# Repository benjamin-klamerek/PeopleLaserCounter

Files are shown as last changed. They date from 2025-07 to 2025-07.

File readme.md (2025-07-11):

# 🧑‍🔬 PeopleLaserCounter

## License

<br />This work is licensed under a <a rel="license" href="http://creativecommons.org/licenses/by-nc-sa/4.0/">Creative Commons Attribution-NonCommercial-ShareAlike 4.0 International License</a>.

## 🎯 Objectif du projet

Système de comptage de personnes utilisant des **capteurs analogiques** (comme des lasers ou photodiodes) et une **carte Arduino**. Il permet de **détecter** et **compter** les passages à l’entrée et à la sortie d’un lieu.

Le compteur peut être :
- Automatiquement mis à jour via des **capteurs analogiques (lasers)**.
- Manuellement contrôlé à l’aide de **boutons physiques**.

L’objectif principal est de **transmettre régulièrement la valeur du compteur par communication RF (Radio Fréquence)** à un système distant.

---

## 🏗️ Architecture du projet

### 📁 Structure des fichiers

```bash
PeopleLaserCounter/
├── include/              # Fichiers d'en-tête génériques (README uniquement ici)
├── lib/                  # Bibliothèques additionnelles (non utilisées dans ce projet)
├── src/                  # Code source principal
│   ├── main.cpp          # Logique principale : détection + envoi RF
│   ├── counter.cpp       # Logique de comptage
│   ├── AnalogButton.cpp  # Détection analogique de type "laser"
│   └── *.h               # Fichiers d'en-tête
├── test/                 # Tests (README uniquement ici)
├── platformio.ini        # Configuration PlatformIO
└── .vscode/              # Config de l’environnement de dev (optionnel)
```

## ⚙️ Fonctionnalités module principal

### 🔌 Capteurs analogiques (Laser/Photodiode)
- 2 capteurs connectés aux broches **A0** et **A1**
- Détection de passage par dépassement d’un seuil : `LASER_THRESHOLD`

### 🔘 Boutons physiques
- **Incrémentation** : broche **2**
- **Décrémentation** : broche **3**
- **Reset long** (appui ≥ 3 secondes) : broche **4**

### 📡 Communication RF
- Utilisation de la bibliothèque **RCSwitch**
- Envoi des données toutes les **15 secondes** (ou à l'utilisation d'un bouton)
  - Modifiable via la constante `GLOBAL_REFRESH_RATE`
- Transmission via la broche **8**

### 🔧 Dépendances
- [`ezButton`](https://github.com/ArduinoGetStarted/ezButton)
- [`RCSwitch`](https://github.com/sui77/rc-switch)
- [`arduino-timer`](https://github.com/contrem/arduino-timer)

## ⚙️ Fonctionnalités module secondaire (compteur)

### 🔌 Afficheur LEDS
- Bandeau de LEDs à la broche **8**

### 📡 Communication RF
- Utilisation de la bibliothèque **RCSwitch**
- Réception via la broche **2**

### 🔧 Dépendances
- [`FastLED`](https://github.com/FastLED/FastLED)
- [`RCSwitch`](https://github.com/sui77/rc-switch)

---

## 📟 PCB

Initialement, le projet devrait être mis sur un seul PCB. Mais ce dernier peut être commun aux 2 modules en sélectionnant uniquement les connexions nécessaires.

[Fichier Gerber](PCB/PeopleLaserCounter-main.zip) qui peut être construit par un service en ligne.

Liste du matériel utilisé : 

- 2 alimentations 220V vers 12V (1A suffit pour le modules avec les lasers, il faut compteur plus pour le module LEDs mais cela dépend aussi du nombre de LEDs par segment)
- 2 Arduino UNO
- 2 modules HCW-P715 (12V vers 5V)
- Des LEDs adressables compatibles Arduino
- Un émetteur et récepteur radio fréquence 433Mhz compatible Arduino
- Des boutons, du fil, des cosses et des connecteurs divers (type jst xh en 2.54mm)

--- 

## 🧩 Les fichiers 3D STL

Vous pouvez trouver des boitiers pour impressions 3D dans le dossier [STL](/STL/)

Des inserts filetés pour vis M5 sont utilisés afin de fermer le boitier.

Les fichiers concernant l'affichage des nombres provient de ce projet : https://github.com/leonvandenbeukel/7-Segment-Digital-Clock-V2

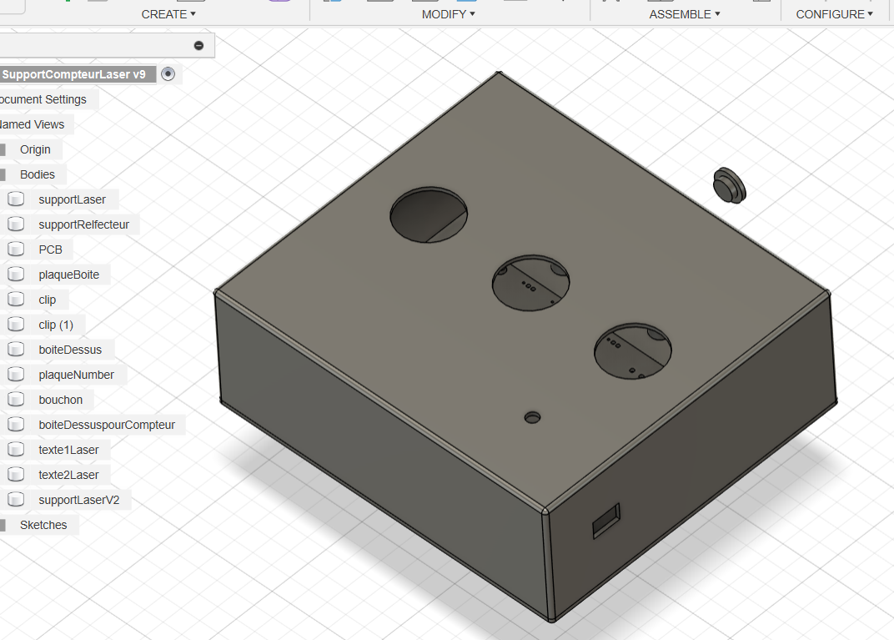
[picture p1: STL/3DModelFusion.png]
3DModel


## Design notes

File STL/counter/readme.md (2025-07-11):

These STL are from https://github.com/leonvandenbeukel/7-Segment-Digital-Clock-V2

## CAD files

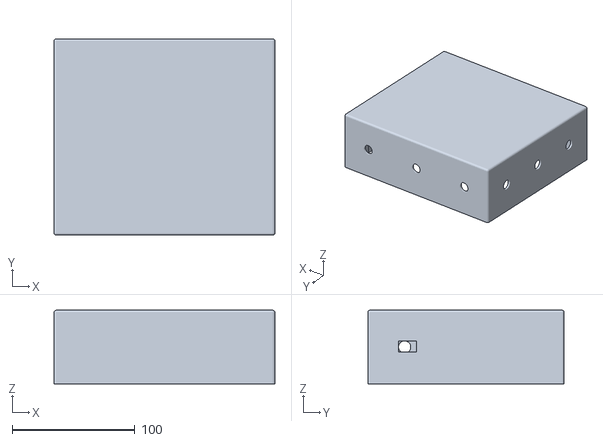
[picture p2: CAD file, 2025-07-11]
STL/boxes/boiteDessuspourCompteur.stl
180.0 x 160.0 x 60.0

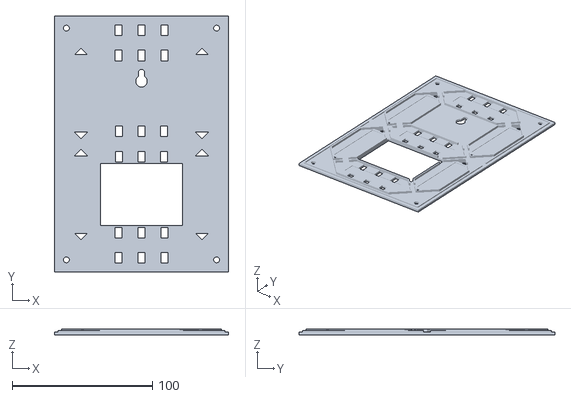
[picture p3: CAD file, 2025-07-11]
STL/counter/Bottom.stl
124.2 x 182.5 x 4.00

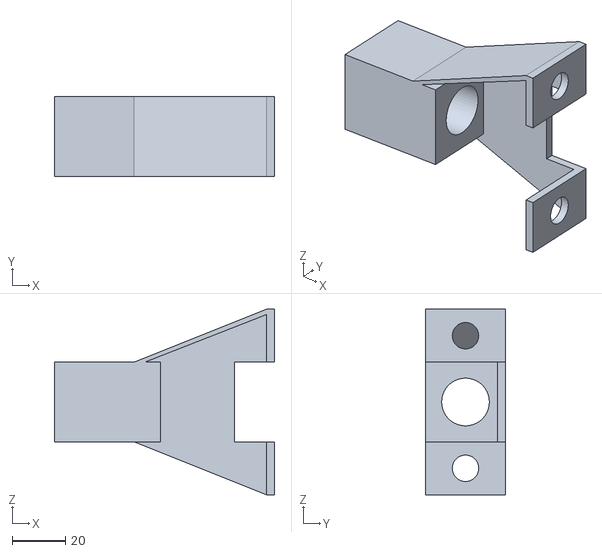
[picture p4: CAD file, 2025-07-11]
STL/boxes/supportLaserV2.stl
83.0 x 30.0 x 70.0

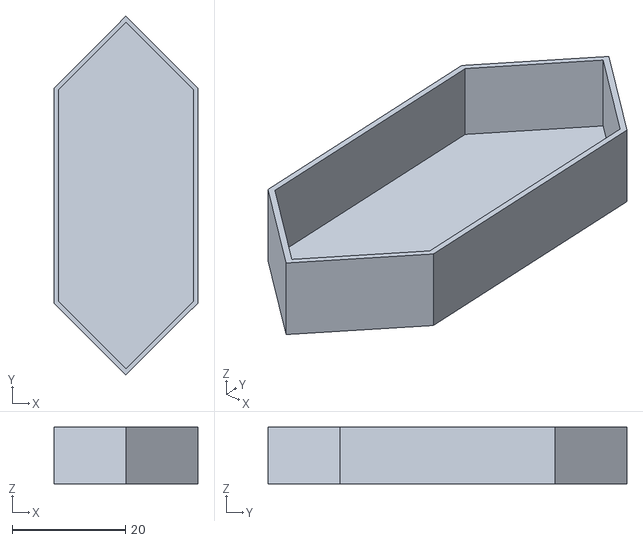
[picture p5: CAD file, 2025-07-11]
STL/counter/Segment_Vert_Flat.stl
25.4 x 63.5 x 10.00

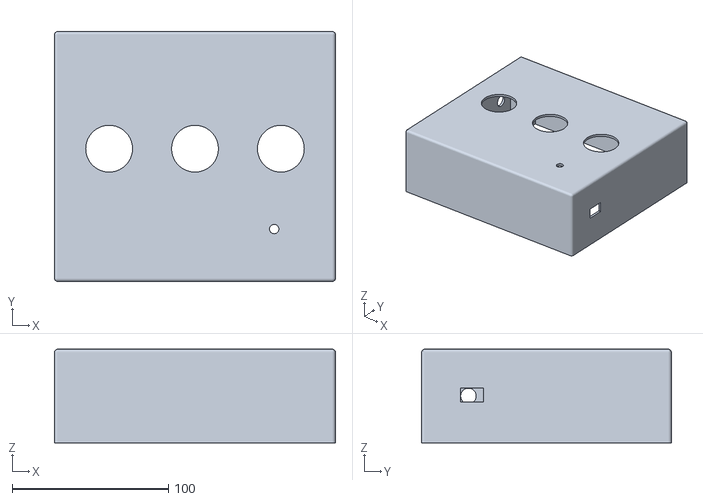
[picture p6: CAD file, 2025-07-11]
STL/boxes/boiteDessus.stl
180.0 x 160.0 x 60.0

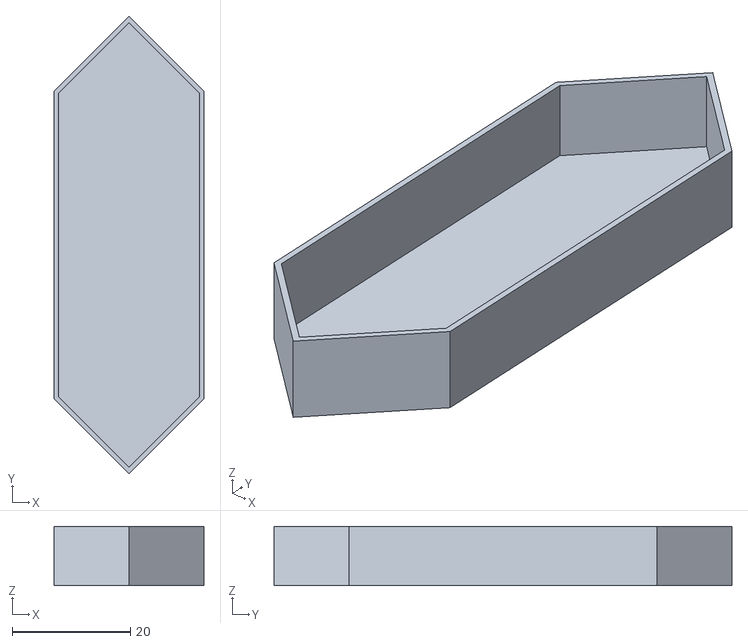
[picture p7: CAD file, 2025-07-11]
STL/counter/Segment_Hor_Flat.stl
25.4 x 77.5 x 10.0

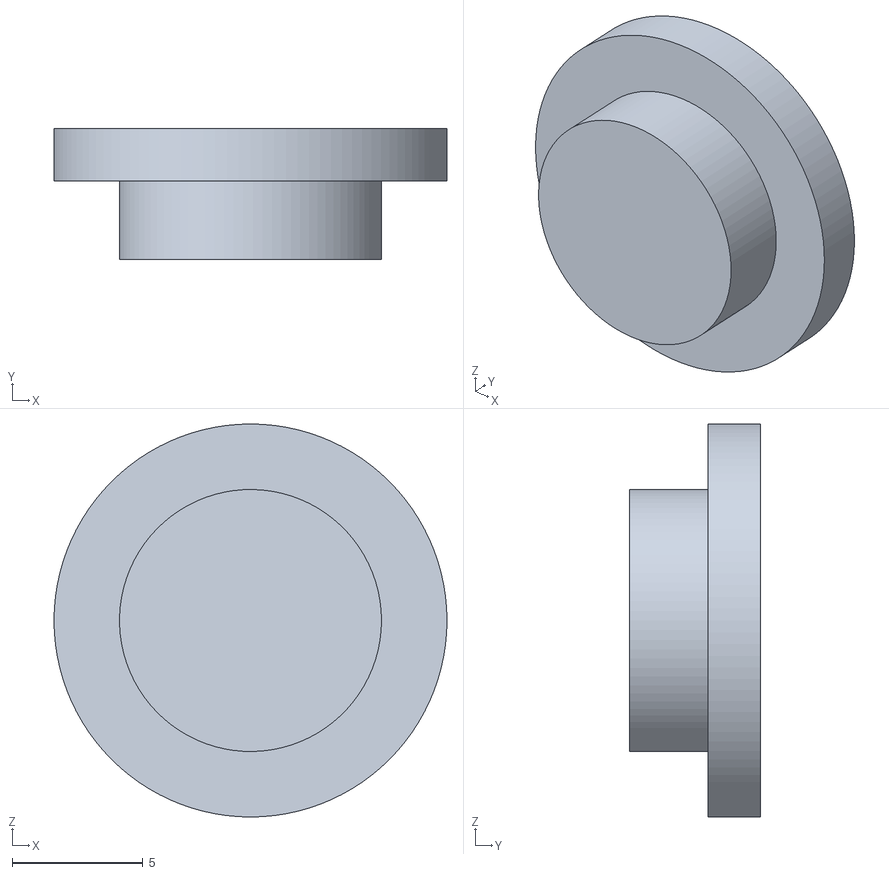
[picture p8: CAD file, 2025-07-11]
STL/boxes/bouchon.stl
15.0 x 5.00 x 15.0

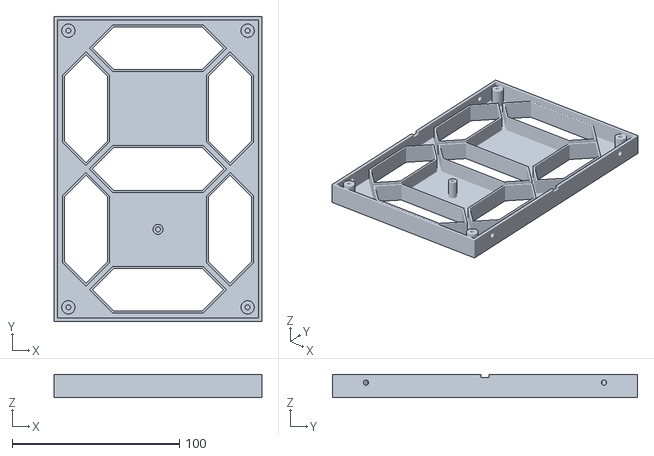
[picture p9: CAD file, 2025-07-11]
STL/counter/Top.stl
124.2 x 182.5 x 14.0

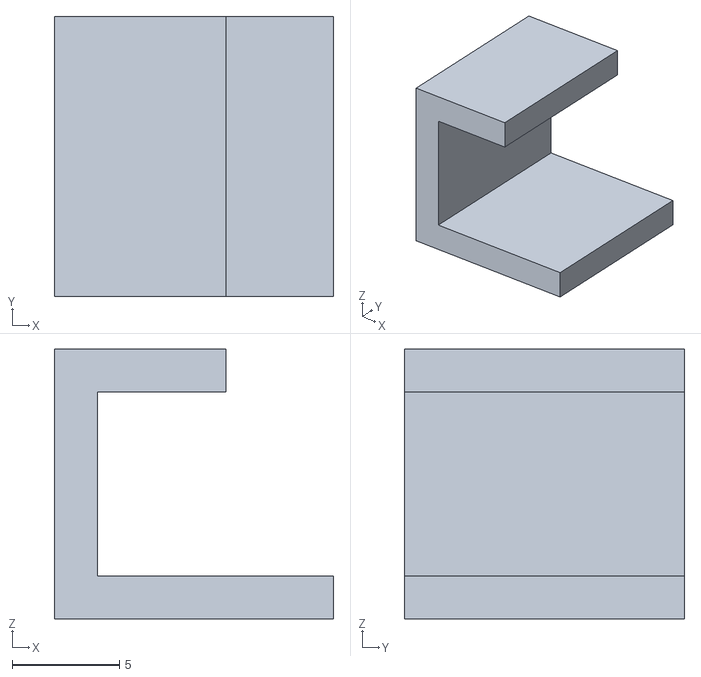
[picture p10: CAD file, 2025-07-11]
STL/boxes/clip.stl
13.0 x 13.0 x 12.5

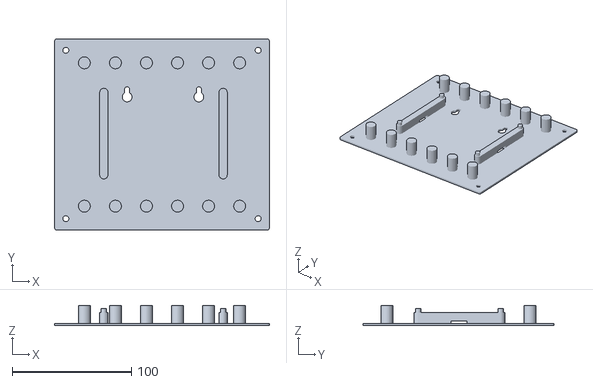
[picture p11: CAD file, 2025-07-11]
STL/boxes/plaqueBoite.stl
180.0 x 160.0 x 17.0

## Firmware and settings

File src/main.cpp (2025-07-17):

#include <Arduino.h>
#include <RCSwitch.h>
#include <ezButton.h>
#include <arduino-timer.h>
#include "AnalogButton.h"

#define COUNTER_LIMIT 1000
#define LASER_THRESHOLD 450
#define INVERT_PIN 6
#define PIN_RC 8
#define NB_BITS_TO_SEND 16
#define GLOBAL_REFRESH_RATE 15000     // ms
#define BUTTON_SHIFT_REFRESH_RATE 500 // ms
#define BUTTON_RESET_LONG_PRESS_TIME 3000 // ms

RCSwitch mySwitch = RCSwitch();

ezButton buttonAddOne(2);
ezButton buttonRemoveOne(3);
ezButton buttonReset(4);

AnalogButton laser1(A0, LASER_THRESHOLD);
AnalogButton laser2(A1, LASER_THRESHOLD);

// To be able to send 0, we use 1 as the first value (which is in fact 0)
int counter = 1;

//Too handle reset button long press
// We need to wait 3 seconds before resetting the counter
unsigned long resetPressStartTime = 0;
bool resetActionDone = true;

// Create a timer for periodic sending
// This timer will send the counter value every GLOBAL_REFRESH_RATE milliseconds
auto timerPeriodicSending = timer_create_default();

// Delay buttons sending to avoid flooding counter
auto timerButton = timer_create_default();

bool sendCounterValues(void *)
{
  mySwitch.send(counter, NB_BITS_TO_SEND);
  Serial.println("Counter SENT !");
  return true;
}

void scheduleNextSend()
{
  timerButton.cancel();
  timerButton.in(BUTTON_SHIFT_REFRESH_RATE, sendCounterValues);
}

void setup()
{
  mySwitch.enableTransmit(PIN_RC);
  mySwitch.setPulseLength(350);
  mySwitch.setProtocol(1);
  mySwitch.setRepeatTransmit(10);
  Serial.begin(9600);

  buttonAddOne.setDebounceTime(50);
  buttonRemoveOne.setDebounceTime(50);
  buttonReset.setDebounceTime(50);

  laser1.setDebounceTime(20);
  laser2.setDebounceTime(20);

  pinMode(INVERT_PIN, INPUT_PULLUP);

  timerPeriodicSending.every(GLOBAL_REFRESH_RATE, sendCounterValues);

  Serial.println("Arduino ready");
}

void increaseCounter()
{
  if (counter < COUNTER_LIMIT)
  {
    counter++;
    Serial.print("Counter increased : ");
    Serial.println(counter);
    scheduleNextSend();
  }
}

void decreaseCounter()
{
  if (counter > 1)
  {
    counter--;
    Serial.print("Counter decreased : ");
    Serial.println(counter);
    scheduleNextSend();
  }
}

void resetCounter()
{
  counter = 1;
  Serial.println("Counter reset to 0");
  sendCounterValues(nullptr);
}

void loopButtons()
{
  buttonAddOne.loop();
  buttonRemoveOne.loop();
  buttonReset.loop();
  if (buttonAddOne.isReleased())
  {
    increaseCounter();
  }
  else if (buttonRemoveOne.isReleased())
  {
    decreaseCounter();
  }

  if (buttonReset.isPressed())
  {
    resetPressStartTime = millis();
    resetActionDone = false;
  }

  if (buttonReset.getState() == LOW)
  {
    if (!resetActionDone && (millis() - resetPressStartTime >= BUTTON_RESET_LONG_PRESS_TIME))
    {
      resetCounter();
      resetActionDone = true;
    }
  }

  if (buttonReset.isReleased())
  {
    resetPressStartTime = 0;
    resetActionDone = false;
  }
}

void loopLasers()
{
  laser1.loop();
  laser2.loop();

  bool invert = digitalRead(INVERT_PIN);

  if (laser1.isPressed())
  {
    if (invert)
    {
      Serial.println("Laser 1 : +1");
      increaseCounter();
    }
    else
    {
      Serial.println("Laser 1 : -1");
      decreaseCounter();
    }
  }

  if (laser2.isPressed())
  {
    if (invert)
    {
      Serial.println("Laser 2 : -1");
      decreaseCounter();
    }
    else
    {
      Serial.println("Laser 2 : +1");
      increaseCounter();
    }
  }
}

void loop()
{
  timerPeriodicSending.tick();
  timerButton.tick();
  loopButtons();
  loopLasers();
}

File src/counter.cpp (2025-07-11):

#include <Arduino.h>
#include <RCSwitch.h>
#include <FastLED.h>

#define COUNTER_LIMIT 1000
#define LIMIT_PEOPLE 60
#define LED_PIN 8
#define NUM_DIGITS 3
#define LEDS_PER_DIGIT 7
#define NUM_LEDS (NUM_DIGITS * LEDS_PER_DIGIT)

CRGB leds[NUM_LEDS];

// Segment order : C, D, E, F, A, B, G
const byte digitSegments[10][7] = {
    {1, 1, 1, 1, 1, 1, 0}, // 0
    {1, 0, 0, 0, 0, 1, 0}, // 1
    {0, 1, 1, 0, 1, 1, 1}, // 2
    {1, 1, 0, 0, 1, 1, 1}, // 3
    {1, 0, 0, 1, 0, 1, 1}, // 4
    {1, 1, 0, 1, 1, 0, 1}, // 5
    {1, 1, 1, 1, 1, 0, 1}, // 6
    {1, 0, 0, 0, 1, 1, 0}, // 7
    {1, 1, 1, 1, 1, 1, 1}, // 8
    {1, 1, 0, 1, 1, 1, 1}  // 9
};

RCSwitch mySwitch = RCSwitch();

void showDigit(byte digitIndex, byte num, CRGB color)
{
    if (digitIndex >= NUM_DIGITS || num > 9)
        return;

    byte offset = digitIndex * LEDS_PER_DIGIT;
    for (byte i = 0; i < LEDS_PER_DIGIT; i++)
    {
        leds[offset + i] = digitSegments[num][i] ? color : CRGB::Black;
    }
}

void showNumber(int number)
{
    CRGB color = CRGB::Green;
    if (number >= LIMIT_PEOPLE)
    {
        color = CRGB::Red;
    }

    for (int i = 0; i < NUM_DIGITS; i++)
    {
        byte digit = number % 10;
        number /= 10;
        showDigit(i, digit, color);
    }
    FastLED.show();
}

void setup()
{
    Serial.begin(9600);

    mySwitch.enableReceive(0); // Enable receiver on interrupt 0 (pin 2)
    Serial.println("RXB12 ready");

    FastLED.addLeds<WS2812, LED_PIN, GRB>(leds, NUM_LEDS);
    FastLED.setBrightness(200);
    FastLED.clear();
    FastLED.show();
    Serial.println("Fast LED ready");

    showNumber(0);

    Serial.println("ARDUINO ready");
}

void loop()
{
    if (mySwitch.available())
    {
        long receivedValue = mySwitch.getReceivedValue();
        if (receivedValue > 0 && receivedValue <= COUNTER_LIMIT)
        {
            Serial.print("Received : ");
            Serial.print(receivedValue);
            Serial.print(" / bit length : ");
            Serial.println(mySwitch.getReceivedBitlength());
            showNumber(receivedValue - 1);
        }
        else
        {
            Serial.println("Out of range");
        }

        mySwitch.resetAvailable();
    }
}
